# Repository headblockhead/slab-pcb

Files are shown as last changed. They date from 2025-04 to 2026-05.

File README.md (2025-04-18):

# Slab PCB



The full PCB, schematics, and gerber downloads for the [Slab keyboard project](https://github.com/headblockhead/slab).

Downloads are in the releases section.

## Layers

- The layer `User.3` stores non-polygon versions of the silkscreen text elements that can be edited.
- The layer `User.6` stores a printable outline of keyswitch locations, so a keymap can be drawn on paper to test the layout.

## Building

This project uses [Nix](https://nixos.org) for CI/CD only, to generate gerber files using KiCAD's CLI.

## Sponsorship

The PCB prototypes for this version of the Slab keyboard project were kindly provided by [PCBX](https://link.pcbx.com/fddd) for free!

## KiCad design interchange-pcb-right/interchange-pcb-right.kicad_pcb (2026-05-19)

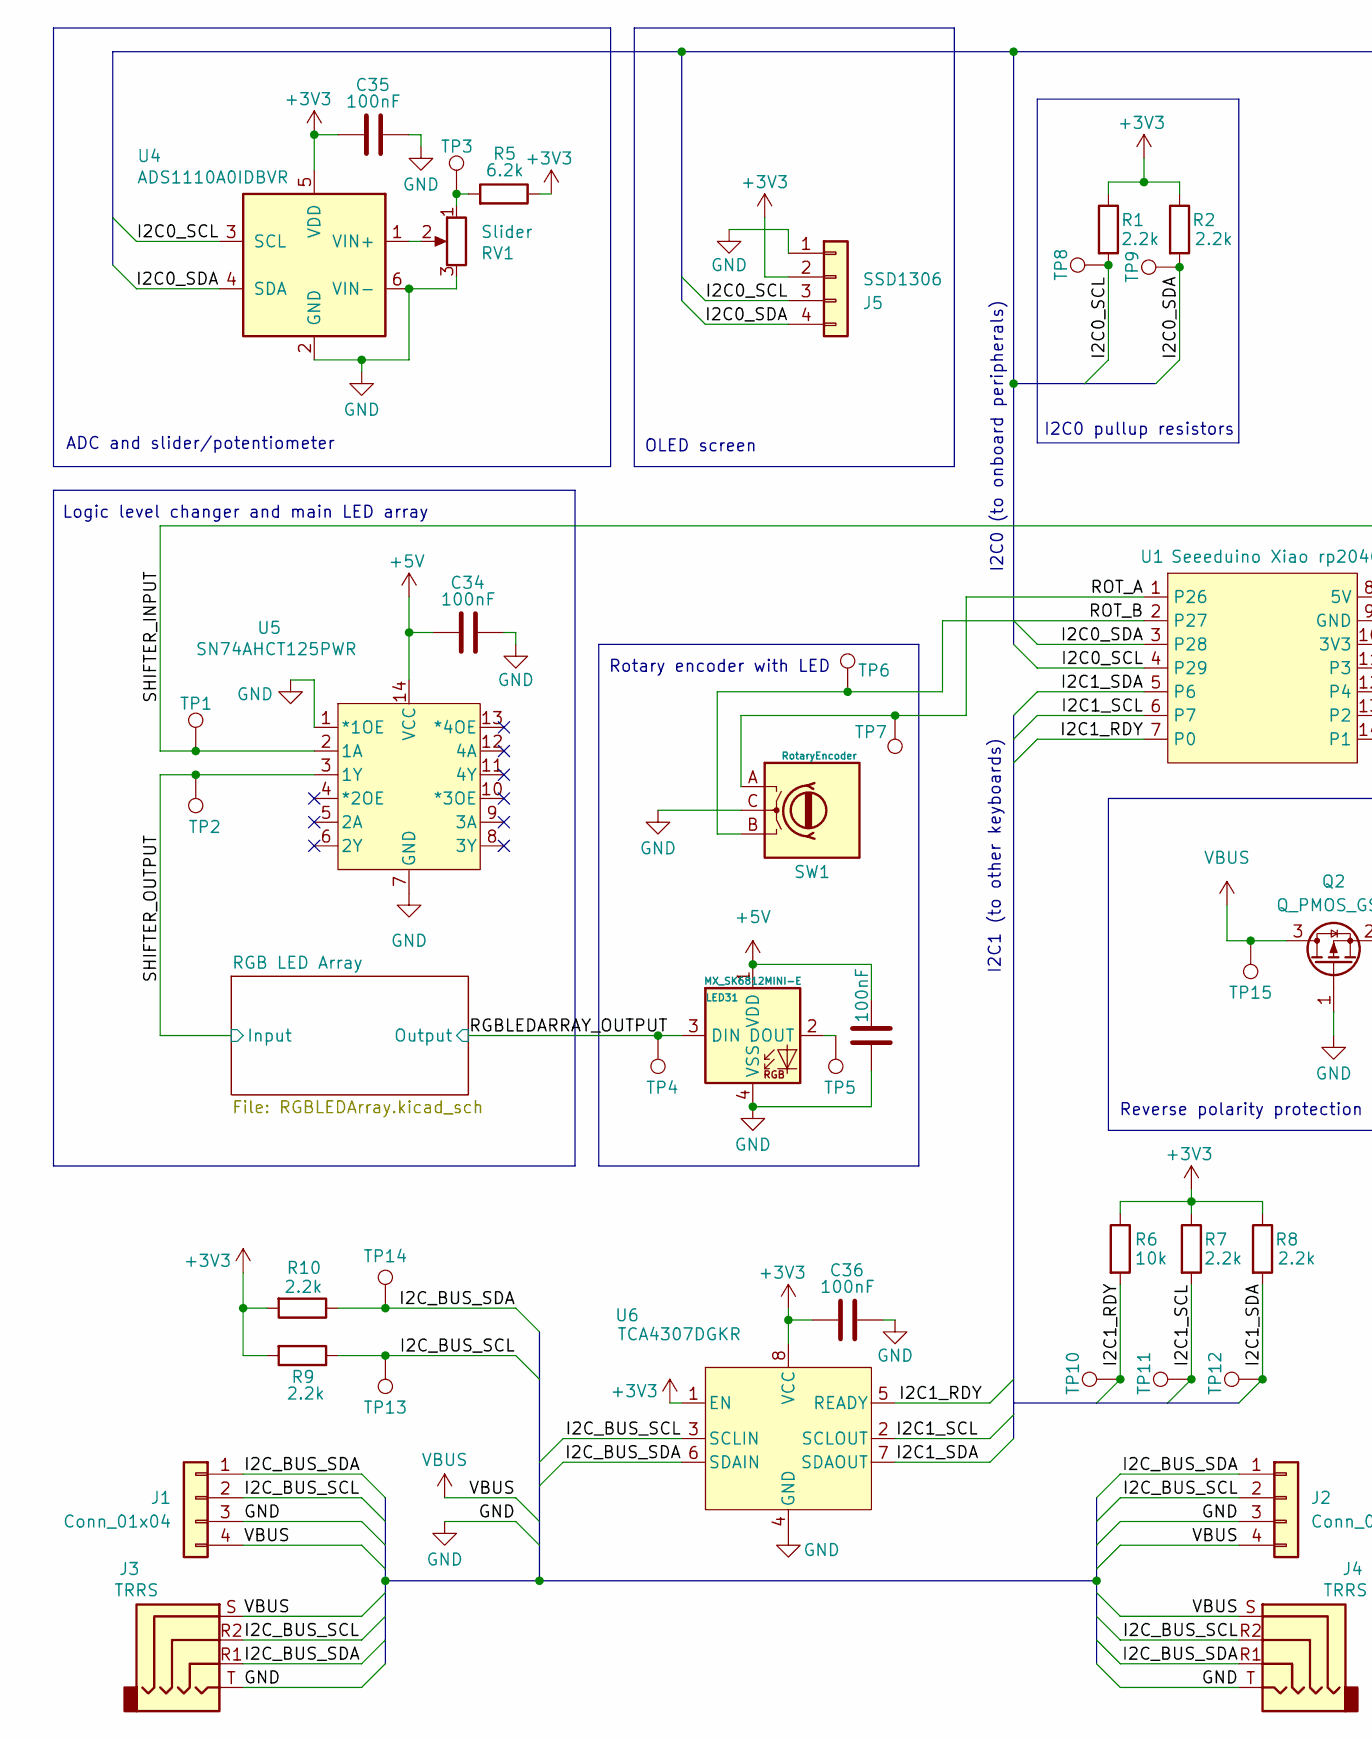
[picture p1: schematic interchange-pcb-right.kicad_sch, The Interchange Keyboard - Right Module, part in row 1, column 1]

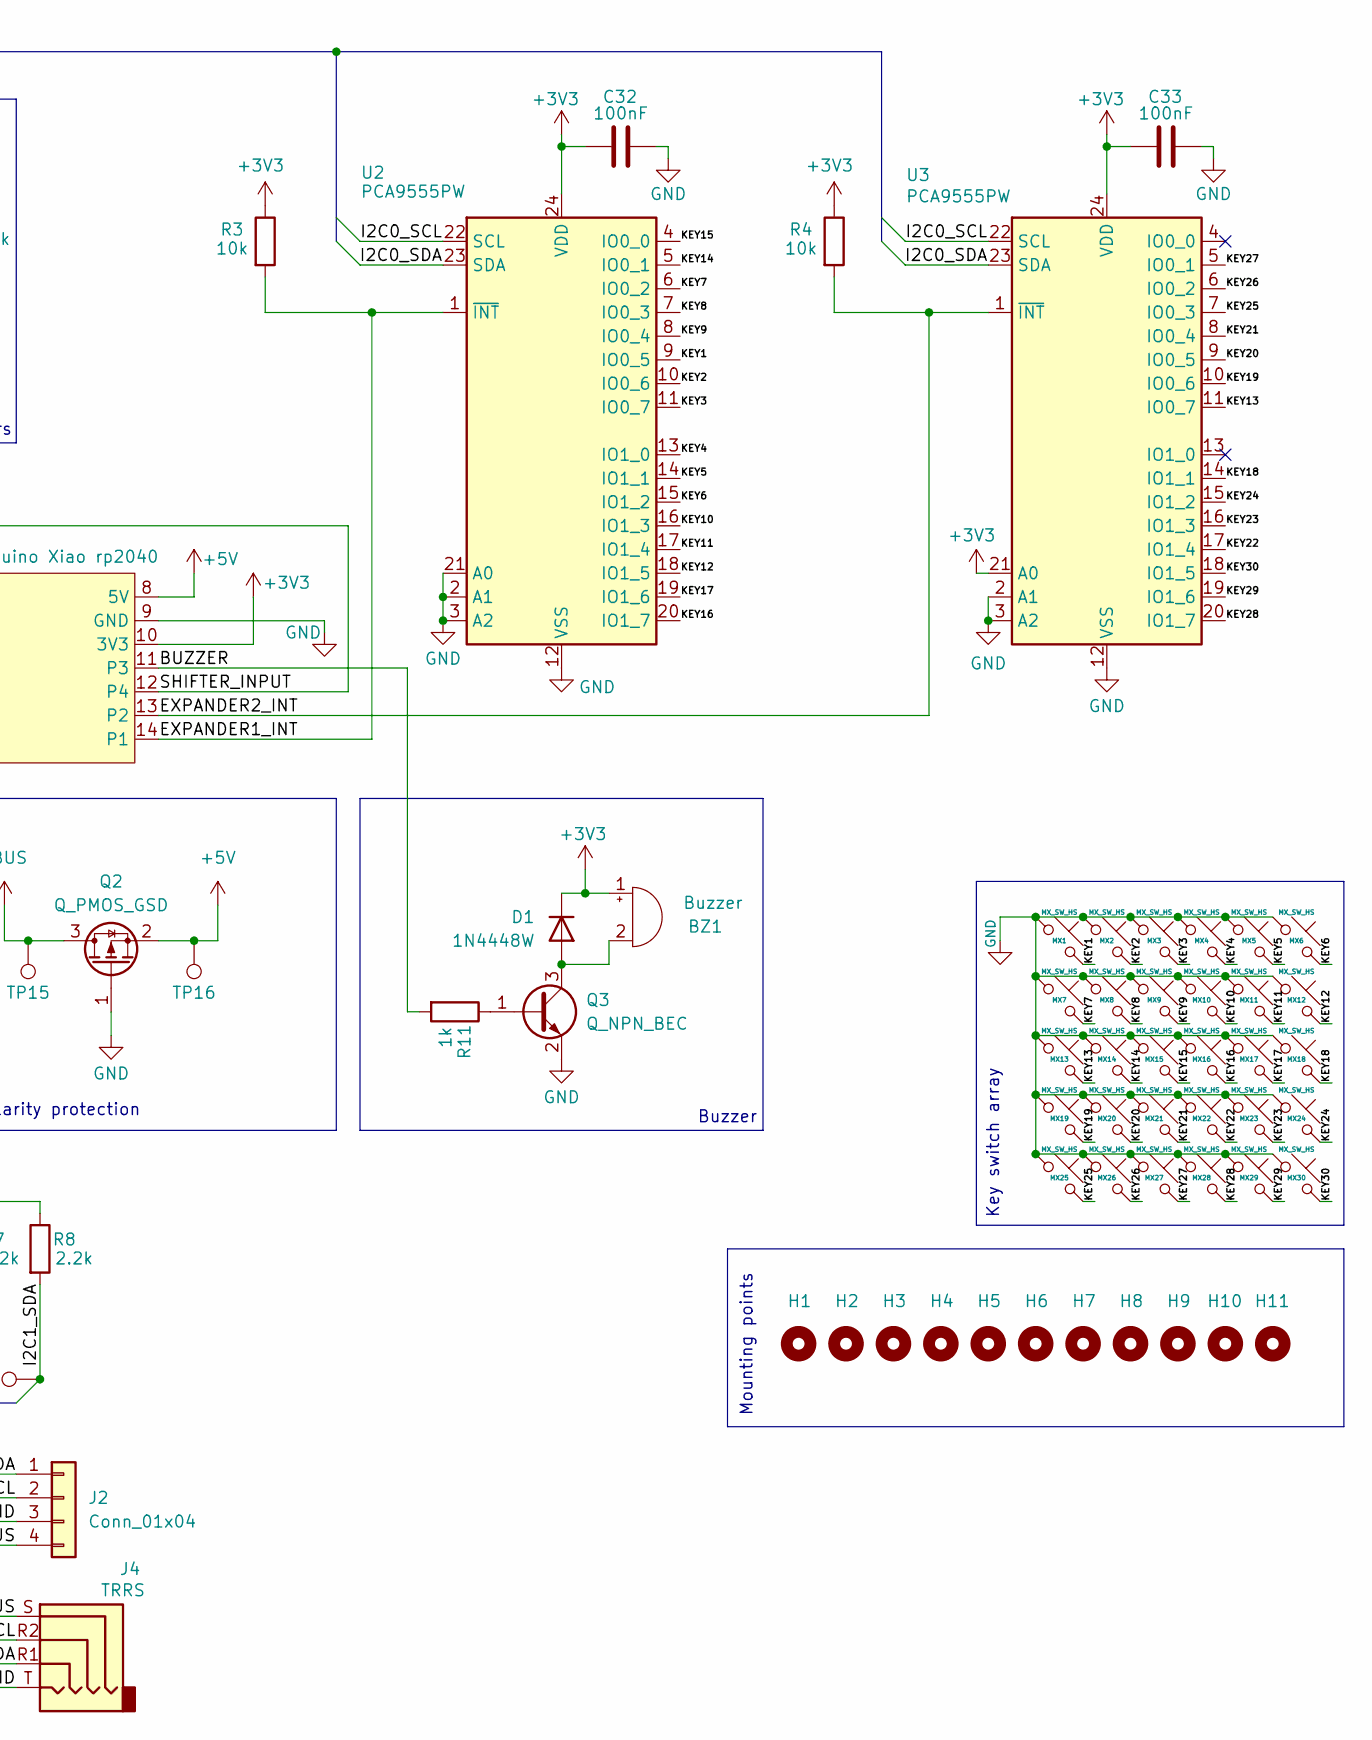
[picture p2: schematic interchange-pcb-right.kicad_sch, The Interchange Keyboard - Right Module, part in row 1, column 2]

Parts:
BZ1: Buzzer; buzzer; LCSC C94599
C31, C32, C33, C34, C35, C36: 100nF; C_0603_1608Metric_Pad1.08x0.95mm_HandSolder; LCSC C14663
D1: 1N4448W; D_SOD-123; LCSC C5190208
H1, H2, H3, H4, H5, H6, H7, H8, H9, H10, H11: MountingHole_Pad; MountingHole_3.2mm_M3
J1: Conn_01x04; MagneticSlot_Right
J2: Conn_01x04; MagneticSlot_Left
J3, J4: TRRS; Jack_3.5mm_KoreanHropartsElec_PJ-320D-4A_Horizontal; LCSC C95562
J5: SSD1306; SSD1306_128x32; LCSC C5248081
LED31: MX_SK6812MINI-E; LED_6028R_Custom; LCSC C5149201
MX1, MX2, MX3, MX4, MX5, MX6, MX7, MX8, MX9, MX10, MX11, MX12, MX13, MX14, MX15, MX16, MX17, MX18, MX19, MX20, MX21, MX22, MX23, MX24, MX25, MX26, MX27, MX28, MX29, MX30: MX_SW_HS; SW_choc_mx_combined; LCSC C41430893
Q2: Q_PMOS_GSD; SOT-23_Handsoldering; LCSC C54157814
Q3: Q_NPN_BEC; SOT-23_Handsoldering; LCSC C57668
R1, R2, R7, R8, R9, R10: 2.2k; R_0603_1608Metric_Pad0.98x0.95mm_HandSolder; LCSC C4190
R3, R4, R6: 10k; R_0603_1608Metric_Pad0.98x0.95mm_HandSolder; LCSC C2930027
R5: 6.2k; R_0603_1608Metric_Pad0.98x0.95mm_HandSolder; LCSC C2907186
R11: 1k; R_0603_1608Metric_Pad0.98x0.95mm_HandSolder; LCSC C2907113
RV1: Slider; SW_RS45111A900F_ALPS; LCSC C470640
SW1: RotaryEncoder; RotaryEncoder_Alps_EC12E_Vertical_H20mm_Custom; LCSC C351235
TP1, TP2, TP3, TP4, TP5, TP6, TP7, TP8, TP9, TP10, TP11, TP12, TP13, TP14, TP15, TP16: TestPoint; TestPoint_Pad_D1.5mm
U1: Seeeduino Xiao rp2040; Xiao_rp2040_AC_Reflow_Custom
U2, U3: PCA9555PW; TSSOP-24_4.4x7.8mm_P0.65mm; LCSC C128392
U4: ADS1110A0IDBVR; SOT-23-6_Handsoldering; LCSC C16598
U5: SN74AHCT125PWR; LCSC C36365
U6: TCA4307DGKR; SOIC8_DGK_TEX; LCSC C880333

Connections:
+3V3: BZ1.1 (+), C32.2, C33.2, C35.2, C36.2, D1.1 (K), J5.2, R1.1, R2.1, R3.1, R4.1, R5.1, R6.1, R7.1, R8.1, R9.2, R10.2, U1.10 (3V3), U2.24 (VDD), U3.21 (A0), U3.24 (VDD), U4.5 (VDD), U6.1 (EN), U6.8 (VCC)
+5V: C31.2, C34.2, LED31.1 (VDD), Q2.2 (S), TP16.1 (1_1), U1.8 (5V), U5.14 (VCC); also elsewhere on the board
/BUZZER: R11.2, U1.11 (P3)
/EXPANDER1_INT: R3.2, U1.14 (P1), U2.1 (~INT)
/EXPANDER2_INT: R4.2, U1.13 (P2), U3.1 (~INT)
/I2C0_SCL: J5.3, R1.2, TP8.1 (1_1), U1.4 (P29), U2.22 (SCL), U3.22 (SCL), U4.3 (SCL)
/I2C0_SDA: J5.4, R2.2, TP9.1 (1_1), U1.3 (P28), U2.23 (SDA), U3.23 (SDA), U4.4 (SDA)
/I2C1_RDY: R6.2, TP10.1 (1_1), U1.7 (P0), U6.5 (READY)
/I2C1_SCL: R7.2, TP11.1 (1_1), U1.6 (P7), U6.2 (SCLOUT)
/I2C1_SDA: R8.2, TP12.1 (1_1), U1.5 (P6), U6.7 (SDAOUT)
/I2C_BUS_SCL: J1.2, J2.2, J3.R2, J4.R2, R9.1, TP13.1 (1_1), U6.3 (SCLIN)
/I2C_BUS_SDA: J1.1, J2.1, J3.R1, J4.R1, R10.1, TP14.1 (1_1), U6.6 (SDAIN)
/KEY1: MX1.2, U2.9 (IO0_5)
/KEY2: MX2.2, U2.10 (IO0_6)
/KEY3: MX3.2, U2.11 (IO0_7)
/KEY4: MX4.2, U2.13 (IO1_0)
/KEY5: MX5.2, U2.14 (IO1_1)
/KEY6: MX6.2, U2.15 (IO1_2)
/KEY7: MX7.2, U2.6 (IO0_2)
/KEY8: MX8.2, U2.7 (IO0_3)
/KEY9: MX9.2, U2.8 (IO0_4)
/KEY10: MX10.2, U2.16 (IO1_3)
/KEY11: MX11.2, U2.17 (IO1_4)
/KEY12: MX12.2, U2.18 (IO1_5)
/KEY13: MX13.2, U3.11 (IO0_7)
/KEY14: MX14.2, U2.5 (IO0_1)
/KEY15: MX15.2, U2.4 (IO0_0)
/KEY16: MX16.2, U2.20 (IO1_7)
/KEY17: MX17.2, U2.19 (IO1_6)
/KEY18: MX18.2, U3.14 (IO1_1)
/KEY19: MX19.2, U3.10 (IO0_6)
/KEY20: MX20.2, U3.9 (IO0_5)
/KEY21: MX21.2, U3.8 (IO0_4)
/KEY22: MX22.2, U3.17 (IO1_4)
/KEY23: MX23.2, U3.16 (IO1_3)
/KEY24: MX24.2, U3.15 (IO1_2)
/KEY25: MX25.2, U3.7 (IO0_3)
/KEY26: MX26.2, U3.6 (IO0_2)
/KEY27: MX27.2, U3.5 (IO0_1)
/KEY28: MX28.2, U3.20 (IO1_7)
/KEY29: MX29.2, U3.19 (IO1_6)
/KEY30: MX30.2, U3.18 (IO1_5)
/RGBLEDARRAY_OUTPUT: LED31.3 (DIN), TP4.1 (1_1); also elsewhere on the board
/ROT_A: SW1.A, TP7.1 (1_1), U1.1 (P26)
/ROT_B: SW1.B, TP6.1 (1_1), U1.2 (P27)
/SHIFTER_INPUT: TP1.1 (1_1), U1.12 (P4), U5.2 (1A)
/SHIFTER_OUTPUT: TP2.1 (1_1), U5.3 (1Y); also elsewhere on the board
GND: C31.1, C32.1, C33.1, C34.1, C35.1, C36.1, J1.3, J2.3, J3.T, J4.T, J5.1, LED31.4 (VSS), MX1.1, MX2.1, MX3.1, MX4.1, MX5.1, MX6.1, MX7.1, MX8.1, MX9.1, MX10.1, MX11.1, MX12.1, MX13.1, MX14.1, MX15.1, MX16.1, MX17.1, MX18.1, MX19.1, MX20.1, MX21.1, MX22.1, MX23.1, MX24.1, MX25.1, MX26.1, MX27.1, MX28.1, MX29.1, MX30.1, Q2.1 (G), Q3.2 (E), RV1.3, SW1.C, U1.9 (GND), U2.2 (A1), U2.3 (A2), U2.12 (VSS), U2.21 (A0), U3.2 (A1), U3.3 (A2), U3.12 (VSS), U4.2 (GND), U4.6 (VIN-), U5.1 (*1OE), U5.7 (GND), U6.4 (GND); also elsewhere on the board
unnamed: BZ1.2 (-), D1.2 (A), Q3.3 (C)
unnamed: LED31.2 (DOUT), TP5.1 (1_1)
unnamed: Q3.1 (B), R11.1
unnamed: R5.2, RV1.1, TP3.1 (1_1)
unnamed: RV1.2, U4.1 (VIN+)
VBUS: J1.4, J2.4, J3.S, J4.S, Q2.3 (D), TP15.1 (1_1)

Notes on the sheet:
I2C0 (to onboard peripherals)
I2C1 (to other keyboards)
Mounting points
OLED screen
Reverse polarity protection
Rotary encoder with LED
Buzzer
I2C0 pullup resistors
ADC and slider/potentiometer
Key switch array
Logic level changer and main LED array

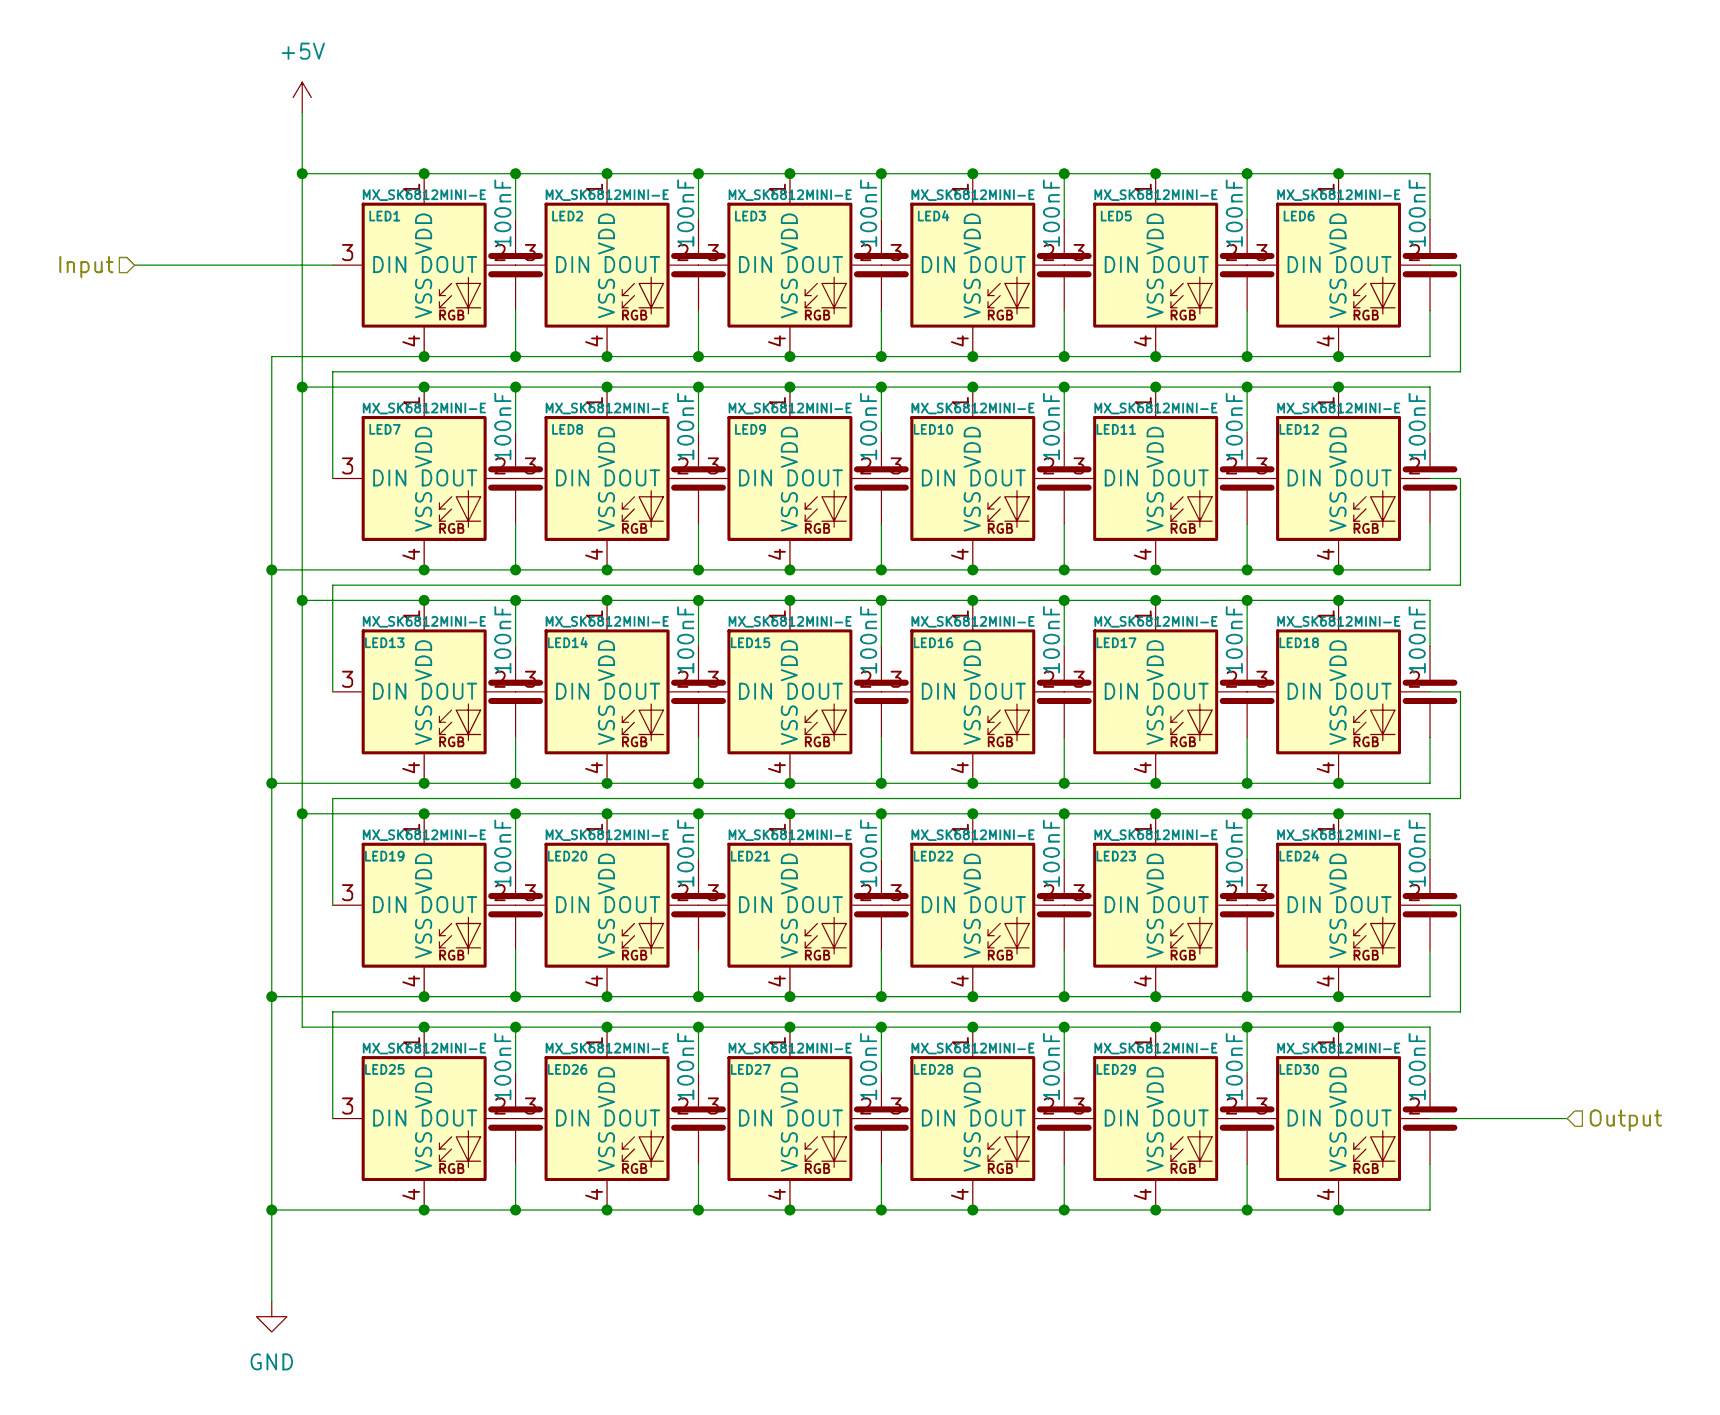
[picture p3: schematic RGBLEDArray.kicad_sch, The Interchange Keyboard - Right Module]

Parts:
C1, C2, C3, C4, C5, C6, C7, C8, C9, C10, C11, C12, C13, C14, C15, C16, C17, C18, C19, C20, C21, C22, C23, C24, C25, C26, C27, C28, C29, C30: 100nF; C_0603_1608Metric_Pad1.08x0.95mm_HandSolder; LCSC C14663
LED1, LED2, LED3, LED4, LED5, LED6, LED7, LED8, LED9, LED10, LED11, LED12, LED13, LED14, LED15, LED16, LED17, LED18, LED19, LED20, LED21, LED22, LED23, LED24, LED25, LED26, LED27, LED28, LED29, LED30: MX_SK6812MINI-E; LED_MX_6028R-ROT_Custom; LCSC C5149201

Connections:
+5V: C1.2, C2.2, C3.2, C4.2, C5.2, C6.2, C7.2, C8.2, C9.2, C10.2, C11.2, C12.2, C13.2, C14.2, C15.2, C16.2, C17.2, C18.2, C19.2, C20.2, C21.2, C22.2, C23.2, C24.2, C25.2, C26.2, C27.2, C28.2, C29.2, C30.2, LED1.1 (VDD), LED2.1 (VDD), LED3.1 (VDD), LED4.1 (VDD), LED5.1 (VDD), LED6.1 (VDD), LED7.1 (VDD), LED8.1 (VDD), LED9.1 (VDD), LED10.1 (VDD), LED11.1 (VDD), LED12.1 (VDD), LED13.1 (VDD), LED14.1 (VDD), LED15.1 (VDD), LED16.1 (VDD), LED17.1 (VDD), LED18.1 (VDD), LED19.1 (VDD), LED20.1 (VDD), LED21.1 (VDD), LED22.1 (VDD), LED23.1 (VDD), LED24.1 (VDD), LED25.1 (VDD), LED26.1 (VDD), LED27.1 (VDD), LED28.1 (VDD), LED29.1 (VDD), LED30.1 (VDD); also elsewhere on the board
/RGBLEDARRAY_OUTPUT: LED30.2 (DOUT); also elsewhere on the board
/SHIFTER_OUTPUT: LED1.3 (DIN); also elsewhere on the board
GND: C1.1, C2.1, C3.1, C4.1, C5.1, C6.1, C7.1, C8.1, C9.1, C10.1, C11.1, C12.1, C13.1, C14.1, C15.1, C16.1, C17.1, C18.1, C19.1, C20.1, C21.1, C22.1, C23.1, C24.1, C25.1, C26.1, C27.1, C28.1, C29.1, C30.1, LED1.4 (VSS), LED2.4 (VSS), LED3.4 (VSS), LED4.4 (VSS), LED5.4 (VSS), LED6.4 (VSS), LED7.4 (VSS), LED8.4 (VSS), LED9.4 (VSS), LED10.4 (VSS), LED11.4 (VSS), LED12.4 (VSS), LED13.4 (VSS), LED14.4 (VSS), LED15.4 (VSS), LED16.4 (VSS), LED17.4 (VSS), LED18.4 (VSS), LED19.4 (VSS), LED20.4 (VSS), LED21.4 (VSS), LED22.4 (VSS), LED23.4 (VSS), LED24.4 (VSS), LED25.4 (VSS), LED26.4 (VSS), LED27.4 (VSS), LED28.4 (VSS), LED29.4 (VSS), LED30.4 (VSS); also elsewhere on the board
unnamed: LED1.2 (DOUT), LED2.3 (DIN)
unnamed: LED2.2 (DOUT), LED3.3 (DIN)
unnamed: LED3.2 (DOUT), LED4.3 (DIN)
unnamed: LED4.2 (DOUT), LED5.3 (DIN)
unnamed: LED5.2 (DOUT), LED6.3 (DIN)
unnamed: LED6.2 (DOUT), LED7.3 (DIN)
unnamed: LED7.2 (DOUT), LED8.3 (DIN)
unnamed: LED8.2 (DOUT), LED9.3 (DIN)
unnamed: LED9.2 (DOUT), LED10.3 (DIN)
unnamed: LED10.2 (DOUT), LED11.3 (DIN)
unnamed: LED11.2 (DOUT), LED12.3 (DIN)
unnamed: LED12.2 (DOUT), LED13.3 (DIN)
unnamed: LED13.2 (DOUT), LED14.3 (DIN)
unnamed: LED14.2 (DOUT), LED15.3 (DIN)
unnamed: LED15.2 (DOUT), LED16.3 (DIN)
unnamed: LED16.2 (DOUT), LED17.3 (DIN)
unnamed: LED17.2 (DOUT), LED18.3 (DIN)
unnamed: LED18.2 (DOUT), LED19.3 (DIN)
unnamed: LED19.2 (DOUT), LED20.3 (DIN)
unnamed: LED20.2 (DOUT), LED21.3 (DIN)
unnamed: LED21.2 (DOUT), LED22.3 (DIN)
unnamed: LED22.2 (DOUT), LED23.3 (DIN)
unnamed: LED23.2 (DOUT), LED24.3 (DIN)
unnamed: LED24.2 (DOUT), LED25.3 (DIN)
unnamed: LED25.2 (DOUT), LED26.3 (DIN)
unnamed: LED26.2 (DOUT), LED27.3 (DIN)
unnamed: LED27.2 (DOUT), LED28.3 (DIN)
unnamed: LED28.2 (DOUT), LED29.3 (DIN)
unnamed: LED29.2 (DOUT), LED30.3 (DIN)

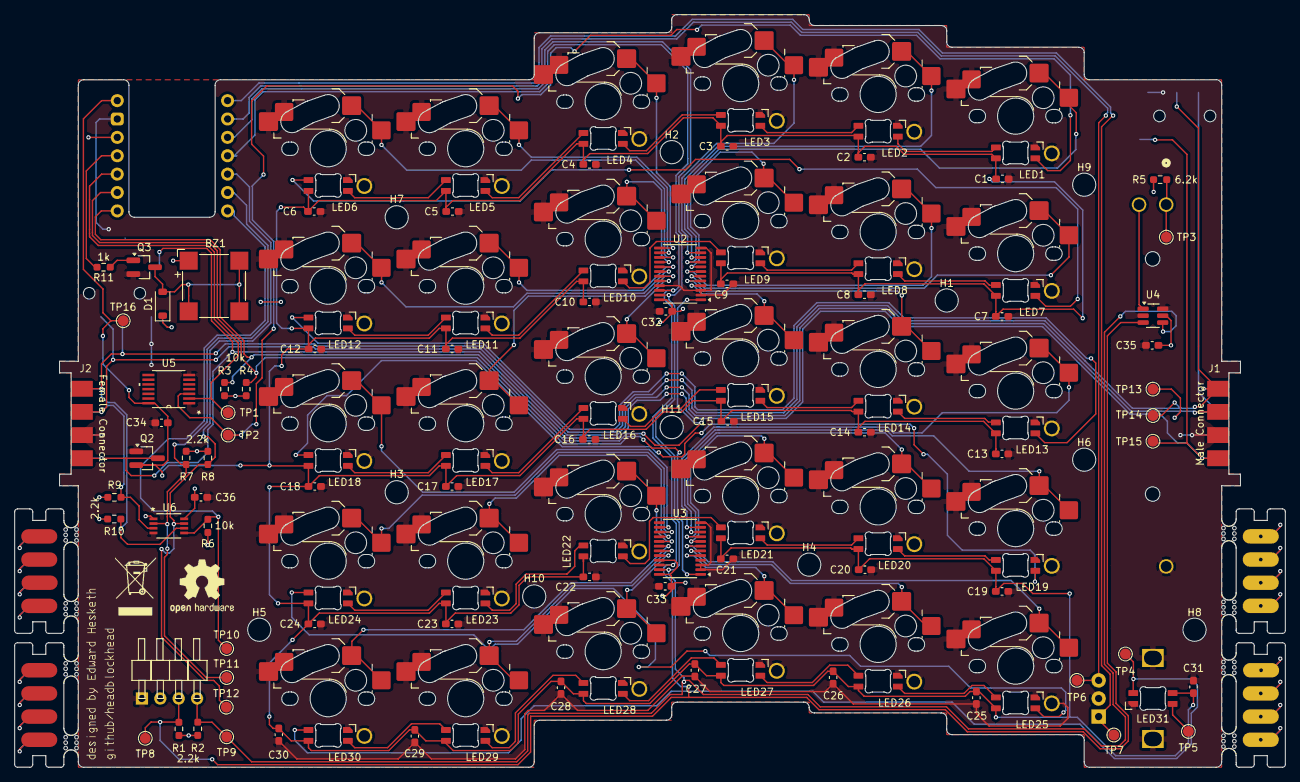
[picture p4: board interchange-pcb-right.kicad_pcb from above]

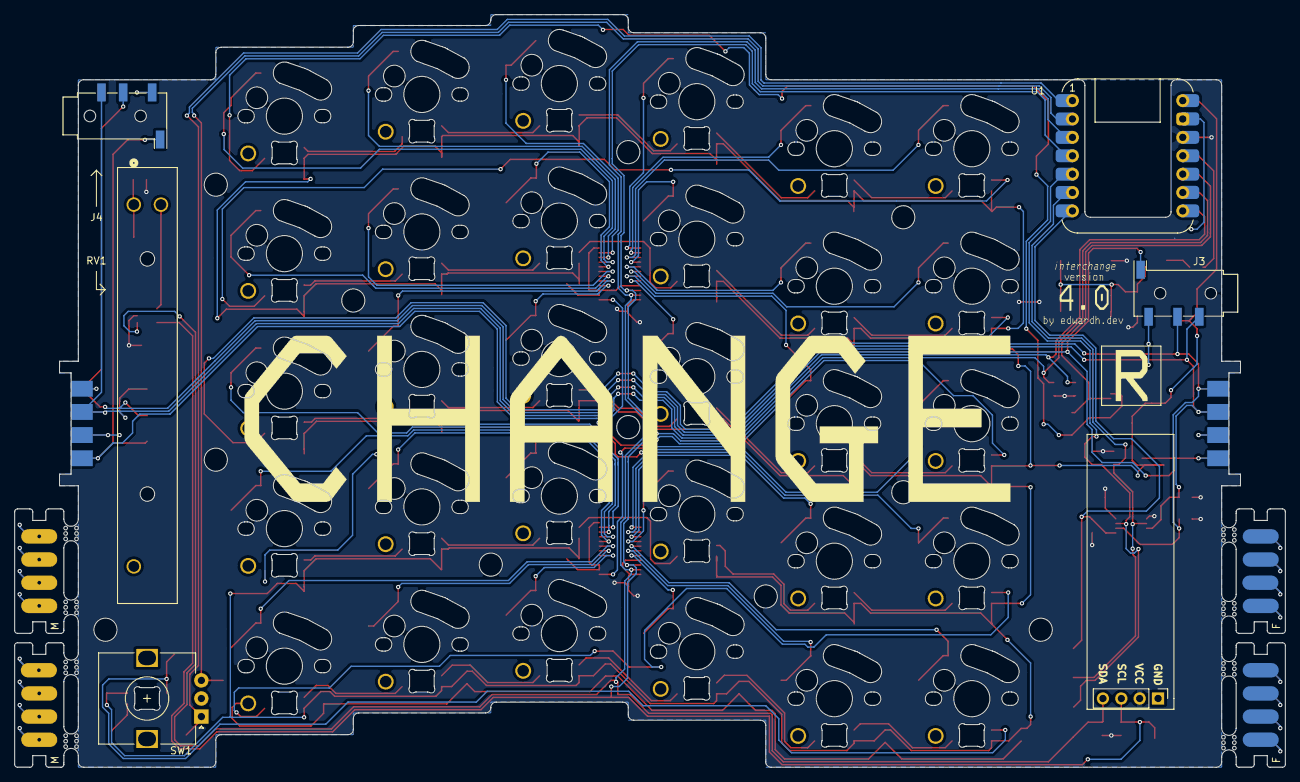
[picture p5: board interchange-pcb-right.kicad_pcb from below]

Board: 2 copper layers, 175.6 x 104.0 mm, 162 parts (6 on the bottom side), 83 nets.

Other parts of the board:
OSHW: OSHW-Logo2_9.8x8mm_SilkScreen
WEEE: WEEE-Logo_5.6x8mm_SilkScreen
mouse-bite-2mm-slot, mouse-bite-2mm-slot#2, mouse-bite-2mm-slot#3, mouse-bite-2mm-slot#4, mouse-bite-2mm-slot#5, mouse-bite-2mm-slot#6, mouse-bite-2mm-slot#7, mouse-bite-2mm-slot#8: VAL**; mouse-bite-2mm-slot

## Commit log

2024-05-25 feat: first commit
    [Slab.kicad_sch]
2024-05-25 feat: update symbol and footprint libraries and add more 3D models
2024-05-25 feat: update schematic symbols
    [Slab.kicad_sch]
2024-09-14 feat: start over with integrated chip
    [Slab.kicad_sch, slab-pcb-left.kicad_pcb, slab-pcb-left.kicad_sch]
2024-09-18 feat: route board
    [slab-pcb-left.kicad_pcb]
2024-09-19 feat: start right board
    [slab-pcb-left.kicad_pcb, slab-pcb-right.kicad_pcb, slab-pcb-right.kicad_sch]
2024-09-21 feat: full left and right boards
    [slab-pcb-left.kicad_pcb, slab-pcb-right.kicad_pcb]
2024-09-22 feat: add hackpad
    [slab-pcb-hackpad.kicad_pcb, slab-pcb-hackpad.kicad_sch, slab-pcb-left.kicad_pcb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]
2024-10-16 fix: inconsistent design
    all modules now share the same design - with updated footprints to
    support both choc+mx PCB mounting holes.
    [slab-pcb-hackpad.kicad_pcb, slab-pcb-hackpad.kicad_sch, slab-pcb-left.kicad_pcb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]
2024-10-16 fix: regen all filled zones, and most DRC
    [slab-pcb-hackpad.kicad_pcb, slab-pcb-left.kicad_pcb, slab-pcb-right.kicad_pcb]
2024-10-20 chore: move shared files to a central directory
    [slab-pcb-hackpad.kicad_pcb, slab-pcb-hackpad.kicad_sch]
2024-10-25 misc: unknown changes to hackpad
    [slab-pcb-hackpad.kicad_pcb]
2024-11-04 fix: upside-down magnetic connectors
    [slab-pcb-hackpad.kicad_pcb, slab-pcb-left.kicad_pcb, slab-pcb-right.kicad_pcb]
2024-11-22 misc hackpad changes
    [slab-pcb-hackpad.kicad_pcb]
2024-11-23 fix: add voltage divider to potentiometer
    [slab-pcb-left.kicad_pcb, slab-pcb-left.kicad_sch, slab-pcb-right.kicad_pcb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]
2024-12-04 feat: update
    [slab-pcb-hackpad.kicad_pcb, slab-pcb-left.kicad_pcb]
2024-12-07 feat: use slots instead of overlapped drill hits
    [slab-pcb-hackpad.kicad_pcb, slab-pcb-hackpad.kicad_sch, slab-pcb-left.kicad_pcb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]
2024-12-07 chore: move via outside of text
    [slab-pcb-hackpad.kicad_pcb]
2024-12-09 feat: bump to 3.2
    [slab-pcb-hackpad.kicad_pcb, slab-pcb-left.kicad_pcb, slab-pcb-right.kicad_pcb]
2025-01-16 feat: convert text to polygon
    Original text is stored on User.3, Silkscreen layers now use polygons to
    remove font requirement.
    [slab-pcb-hackpad.kicad_pcb, slab-pcb-left.kicad_pcb, slab-pcb-right.kicad_pcb]
2025-03-09 feat: add User.6 as printable layout helper
    [slab-pcb-left.kicad_pcb, slab-pcb-left.kicad_sch, slab-pcb-right.kicad_pcb]
2025-04-16 feat: start on v4, updated: right-hand schematic
    [RGBLEDArray.kicad_sch, slab-pcb-left.kicad_pcb, slab-pcb-left.kicad_sch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]
2025-04-16 feat: route most of slab-pcb-right
    [RGBLEDArray.kicad_sch, slab-pcb-right.kicad_pcb, slab-pcb-right.kicad_sch]
2025-04-16 feat: restart slab-pcb-right routing, allign components
    [slab-pcb-right.kicad_pcb, slab-pcb-right.kicad_sch]
2025-04-17 feat: route keys of slab-right
    [slab-pcb-right.kicad_pcb]
2025-04-17 feat: finish routing slab-pcb-right
    [slab-pcb-right.kicad_pcb]
2025-04-18 feat: finialise slab-pcb-right
    [slab-pcb-right.kicad_pcb]
2025-04-18 feat: rename right to interchange
    [RGBLEDArray.kicad_sch, interchange-pcb-right.kicad_pcb, interchange-pcb-right.kicad_sch]
2025-04-18 feat: add connectors to pcb-right using snap-off mousebites
    [interchange-pcb-right.kicad_pcb]
2025-04-18 docs(README): add purpose of user layers
    [interchange-pcb-right.kicad_pcb]
2025-04-19 feat: round connector pads, add resistor values + silkscreen gfx
    [interchange-pcb-right.kicad_pcb]
2025-04-19 fix(right): delete tiny extra piece of copper
    [interchange-pcb-right.kicad_pcb]
2025-04-23 chore: rename slab-pcb-hackpad -> interchange-pcb-hackpad
    [interchange-pcb-hackpad.kicad_pcb, interchange-pcb-hackpad.kicad_sch]
2025-04-23 feat: create schematic for interchange-pcb-hackpad
    and fix minor spacing issues with capaicitors in interchange-pcb-right
    [RGBLEDArray.kicad_sch, interchange-pcb-hackpad.kicad_pcb, interchange-pcb-hackpad.kicad_sch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]
2025-05-05 feat(right): add LCSC part numbers to schematics
    [RGBLEDArray.kicad_sch, interchange-pcb-hackpad.kicad_pcb, interchange-pcb-right.kicad_pcb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]
2026-05-17 wip: add reverse polarity protection and fix buzzer
    [RGBLEDArray.kicad_sch, interchange-pcb-right.kicad_pcb, interchange-pcb-right.kicad_sch]
2026-05-19 feat(right): add more mounting holes
    [interchange-pcb-right.kicad_pcb, interchange-pcb-right.kicad_sch]
2026-05-25 wip: create testing board
    [interchange-connector-test.kicad_pcb, interchange-connector-test.kicad_sch]
